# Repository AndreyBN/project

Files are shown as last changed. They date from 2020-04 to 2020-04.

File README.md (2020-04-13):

# project

The controller module board is a universal tool based on the STM32F107VCT6 microcontroller, designed to be integrated into various systems as a control unit.
The controller module has the following parameters:
• STM32F107VCT6 microcontroller: 72 MHz Cortex-M3, 256 Kbytes of program flash memory, 64 Kbytes of RAM, two 12-bit ADCs (16 external channels), two-channel 12-bit DACs, Ethernet MAC 10/100, USB OTG, 2xCAN, 5x USART , 3x SPI, I2C, SDIO, LQFP100 package;
• USB OTG port with mini USB connector;
• 2 CAN interfaces;
• USB bridge - USART to FT232RL;
• 2 RS-232 interfaces or 2 RS-422/485 interfaces with galvanic isolation;
• 10 / 100MBod RMII PHY with Ethernet RJ-45;
• card slots SD / MMC and microSD;
• 16 lines of the microcontroller's PE port are connected to the connector;
• 3 SPI interface connectors for connecting external devices;
• 25 MHz quartz crystal;
• clock quartz resonator 32768 Hz;
• Reset button;
• JTAG connector for connecting a JTAG programmer or debugger;
• supply voltage +9 V or +5 V;
• power supply to the controller core from a 3 V battery;
• overall dimensions: 160x125 mm; landing dimensions: 150x115 mm.

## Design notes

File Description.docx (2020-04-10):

# 1. МОДУЛЬ КОНТРОЛЛЕРА

Плата модуля контроллера является универсальным средством на базе микроконтроллера STM32F107VCT6, предназначенным для встраивания в различные системы в качестве узла управления.

Модуль контроллера имеет следующие параметры:

- микроконтроллер STM32F107VCT6: 72 МГц Cortex-M3, 256 Кбайт флэш-памяти программ, 64Кбайта ОЗУ, два 12-разрядных АЦП (16 внешних каналов), два 12-разрядных ЦАП, Ethernet MAC 10/100, USB OTG, 2xCAN, 5х USART, 3х SPI, I2C, SDIO, корпус LQFP100;
- порт USB OTG с разъемом mini USB;
- 2 CAN интерфейса;
- Мост USB - USART на FT232RL;
- 2 RS-232-интерфейса или 2 RS-422/485-интерфейса с гальванической изоляцией;
- 10/100МБод RMII PHY с разъемом Ethernet RJ-45;
- слоты карт памяти SD/MMC и microSD;
- 16 линий порта PE микроконтроллера выведено на разъем;
- 3 разъема интерфейса SPI для подключения внешних устройств;
- 25 МГц кварцевый резонатор;
- часовой кварцевый резонатор 32768 Гц;
- кнопка сброса Reset;
- разъем JTAG для подключения JTAG-программатора или отладчика;
- напряжение питания +9 В или +5 В;
- питание ядра контроллера от батарейки 3 В;
- габаритные размеры: 160х125 мм; посадочные размеры: 150х115 мм.

Структурная схема модуля контроллера показана на рисунке 1.

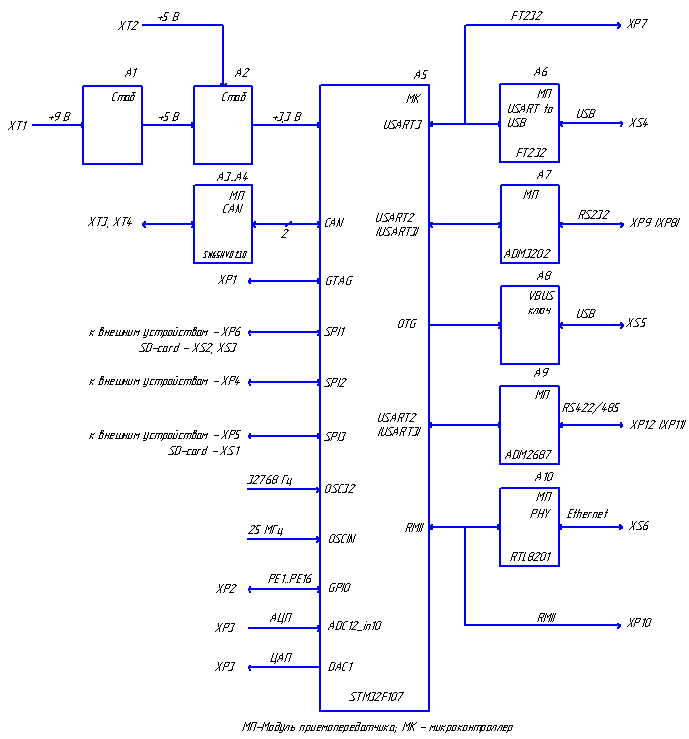
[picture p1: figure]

Рисунок 1 – Структурная схема модуля контроллера

Плата модуля контроллера показана на рисунке 2.

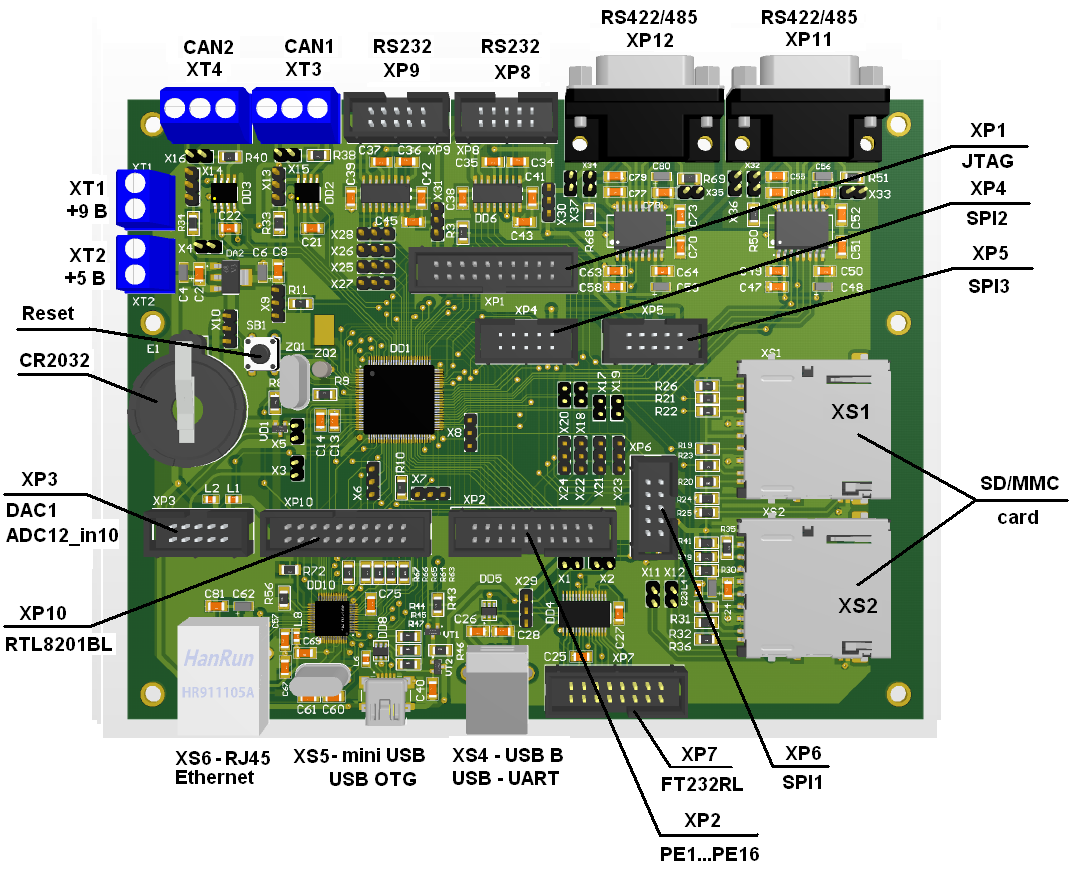
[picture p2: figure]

Рисунок 2 – Плата модуля контроллера

## 1.1 Питание модуля контроллера

Напряжение питания подается через разъемы питания XT1 или XT2. К разъему XT1 подается напряжение от +7,5 до +9 В. К разъему XT2 подается напряжение + 5 В. Для подачи питания +9 В необходимо установить перемычку на X4. Для питания ядра микроконтроллера от батарейки CR2032 необходимо установить перемычку на X10.

Таблица 1 – Установка перемычек на X10

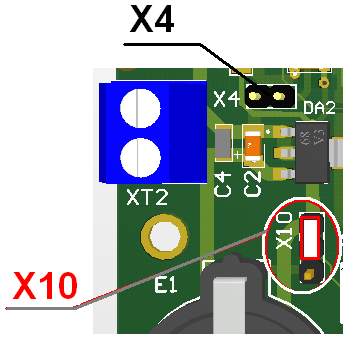
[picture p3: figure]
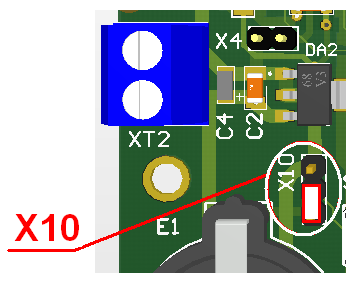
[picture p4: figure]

| Питание ядра от 3,3 В | | Питание ядра от батарейки

## 1.2 Адрес старта микроконтроллера

Кнопка Reset предназначена для сброса микроконтроллера. Установка перемычек на X7 и X9 (рисунок 3) определяет адрес старта микроконтроллера (таблица 2).

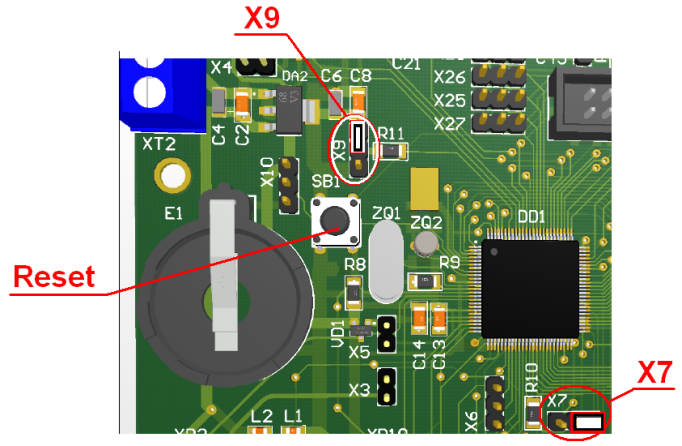
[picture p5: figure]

Рисунок 3 – Установка перемычек на X7 и X9

Таблица 2 – Задание адреса старта микроконтроллера с помощью перемычек X7, X9

X7 (BOOT1) | X9 (BOOT0) | X7 (BOOT1) | X9 (BOOT1) | Функция
| Х | 0 | Х | Программа стартует из основной флэш-памяти (рисунок 3)
| | 1 | 0 | Программа стартует из системной памяти
| | 1 | 1 | Программа стартует из внутреннего ОЗУ

X – любое значение

## 1.3 CAN интерфейс

Установленные на плате микросхемы SN65HVD230 отвечают за преобразование уровней встроенного в микроконтроллер приемопередатчика шины CAN. Структурная схема подключения CAN интерфейса отображена на рисунке 3. Для подключения согласующего резистора R устанавливается перемычка S.

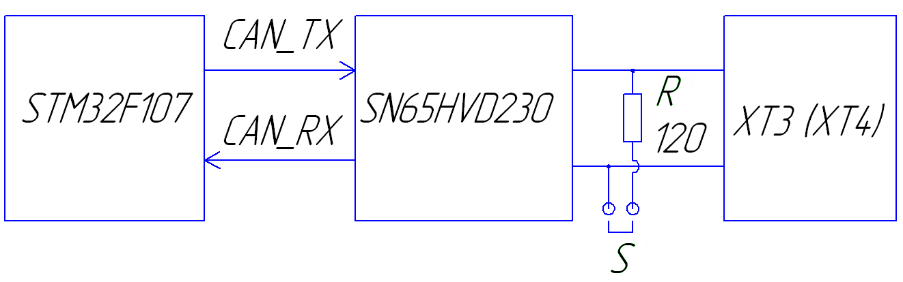
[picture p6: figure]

Рисунок 3 – Структурная схема подключения CAN-интерфейса.

На рисунке 4 показано направление нумерации выводов разъема XT3 и XT4. Для подключения согласующих резисторов устанавливаются перемычки на штыри X15, X16.

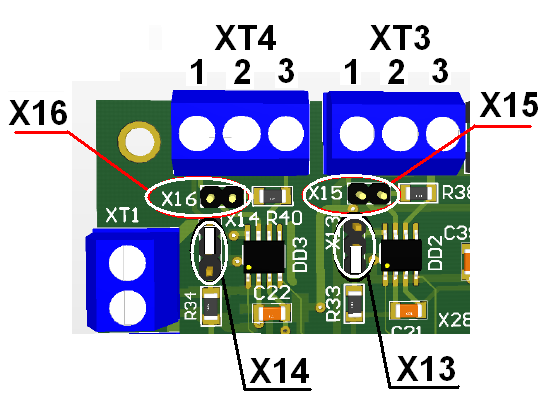
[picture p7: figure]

Рисунок 4 – Направление нумерации выводов разъема XT3 и XT4

Установкой перемычек на штыри X13 и X14 определяет режим работы микросхемы CAN – трансивера.

Таблица 3 – Установка перемычек на X13 и X14

| Высокоскоростной режим работы (Х14 на рисунке 4)
| Режим хранения (Х13 на рисунке 4)

Назначение выводов разъема XT3 (XT4) отображено в таблице 4.

Таблица 4 – Назначение контактов разъема ХT3 (XT4)

Номер контакта | Цепь | Примечание
1 | CANH
2 | GND
3 | CANL

## 1.4 RS232 интерфейс

Установленные на плате микросхемы приемопередатчики ADM3202 отвечают за преобразование уровней встроенного в микроконтроллер приемопередатчика USART в уровни сигналов интерфейса RS232.

Технические характеристики ADM3202:

- Скорость передачи данных 460 кбит/с;
- Конденсаторы накачки заряда 0.1 мкФ;
- Замещение MAX3222/32 и LTC1385;
- Защита от электростатического разряда в соответствии с IEC1000-4-2 (801.2) по выводам RS-232:

±8 кВ: Контактный разряд
±15 кВ: Бесконтактный разряд

Назначение выводов разъемов XP8, XP9 отображено в таблице 5.

Таблица 5 – Назначение контактов разъема ХP8 (XP9)

Номер контакта | Цепь | Примечание
1
2
3 | RS232_RXD
4 | RS232_RTS
5 | RS232_TXD
6 | RS232_CTS
7
8 | +5V
9 | GND
10 | GND

Для питания микросхемы ADM3202 от 3,3 В перемычки выбора напряжения питания Х30 и Х31 должны быть установлена в соответствии с рисунком 5.

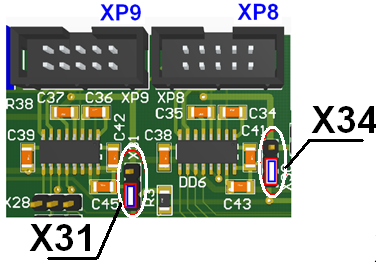
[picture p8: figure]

Рисунок 5 – Установка перемычек на X31 и X34

Для подключения каналов RS232 микроконтроллера необходимо установить перемычки на X21…X24 для подключения к разъему XP8, и на X25…Х28 для подключения к разъему XP9 так, как показано на рисунке 6. Установка перемычек X21…X24 в положение подключает микросхему ADM3202 канала XP8 к приемопередатчику микроконтроллера USART3. Установка перемычек X25…X28 в положение подключает микросхему ADM3202 канала XP9 к приемопередатчику микроконтроллера USART2.

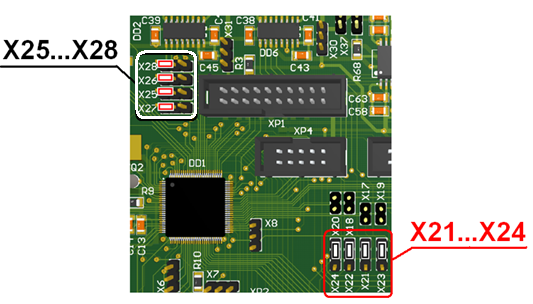
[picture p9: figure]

Рисунок 6 – Установка перемычек на X21…X24 и X25…X28

## 1.5 RS422/485 интерфейс

Установленные на плате микросхемы приемопередатчики ADM2682E отвечают за преобразование уровней встроенного в микроконтроллер приемопередатчика USART в уровни сигналов интерфейса RS422/485.

Изделия ADM2682E/ADM2687E фирмы Analog Devices представляют собой полностью интегральные приёмопередатчики данных с эффективным 5 кВ сигналом и изолированным питанием, имеющие ±15 кВ ESD защиту и пригодные для сверхскоростной связи на многопунктовых линиях передачи.

Каждое из изделий ADM2682E/ADM2687E содержит интегральный изолированный DC-DC преобразователь. В приборах интегрирована технология iCoupler® фирмы Analog Devices, Inc., сочетающая в одном корпусе 3-канальный вентиль, трёхступенчатый дифференциальный драйвер линии, дифференциальный входной приёмник и разработанный фирмой Analog Devices преобразователь постоянного напряжения isoPower®. Микросхема питаются от одиночного источника питания 5 В или 3.3 В, производящего полностью интегральный сигнал, представляя собой RS-422/485 решение с развязкой по цепям питания.

Характерные особенности и преимущества

- Изолированный RS-485/RS-422 приёмопередатчик с эффективным 5 кВ сигналом, с конфигурацией в виде полудуплексной или дуплексной связи;
- Интегральный изолированный преобразователь постоянного напряжения isoPower® ;
- ±15 кВ ESD защита на выводах RS-485 вход/выход;
- Соответствует требованиям стандартов ANSI/TIA/EIA-485-A-98 и ISO 8482:1987(E);
- Питание от 5 В или 3.3 В;
- Соединяет до 256 узлов на одной шине;
- Входы приёмника предохранены от размыкания и КЗ и отказов;
- Высокая стойкость к переходным процессам в синфазном режиме: >25 кВ/мксек;
- Скорость передачи данных: 500 кБит/сек ADM2682E для до 16 Mбит/сек для ADM2687E.

Для подключения интерфейсных микросхем ADM2682E к микроконтроллеру необходимо установить перемычки. Для подключения приемопередатчика USART3 микроконтроллера к микросхеме канала XP11 установить перемычки на X17…X20. Для подключения приемопередатчика USART2 к микросхеме канала XP12 установить перемычки на X25…Х28 в положение , как показано на рисунке 7.

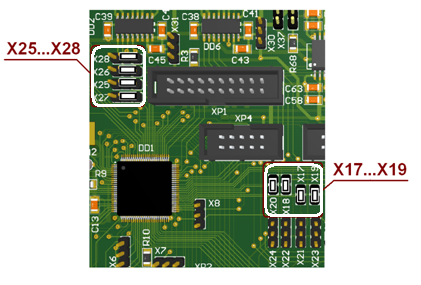
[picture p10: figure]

Рисунок 7 – Установка перемычек на X17…X20 и X25…X28

Назначение выводов разъемов XP11, XP12 (DRB-9MA) отображено в таблице 6.

Таблица 6 – Назначение контактов разъема ХP8 (XP9)

Номер контакта | Цепь | Примечание
1 | RS422/485_TX1+
2 | RS422/485_TX1-
3 | RS422/485_GND
4 | RS422/485_RX1-
5 | RS422/485_RX1+
6 | RS422/485_GND
7 | RS422/485_GND
8 | RS422/485_+5V | Не используется
9 | RS422/485_GND

Структурная схема подключения 4-проводного RS422 – интерфейса показана на рисунке 8. Установкой перемычек подключаются согласующие резисторы.

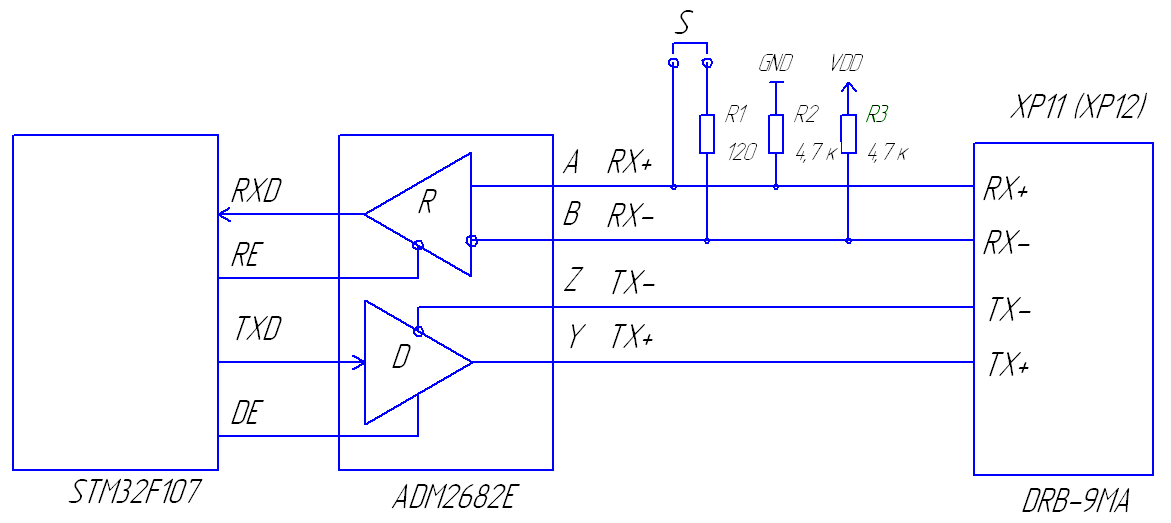
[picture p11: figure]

Рисунок 8 – Структурная схема подключения RS422-интерфейса.

Для подключения к цепям RX+ и RX- каналов XP11 и XP12 согласующего резистора установить перемычки на X34 и X32 в соответствии с рисунком 9.

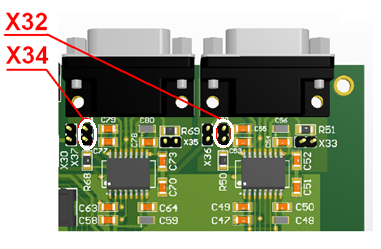
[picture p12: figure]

Рисунок 9 – Установка перемычек на X32 и X34

Примечание. Для реализации 2-проводного RS485 интерфейса необходимо соединить линии RX- и TX- и линии RX+ и TX+ так, как показано на рисунке 10. Для этого соединить в кабельном разъеме контакты 1,5 и 2, 4.

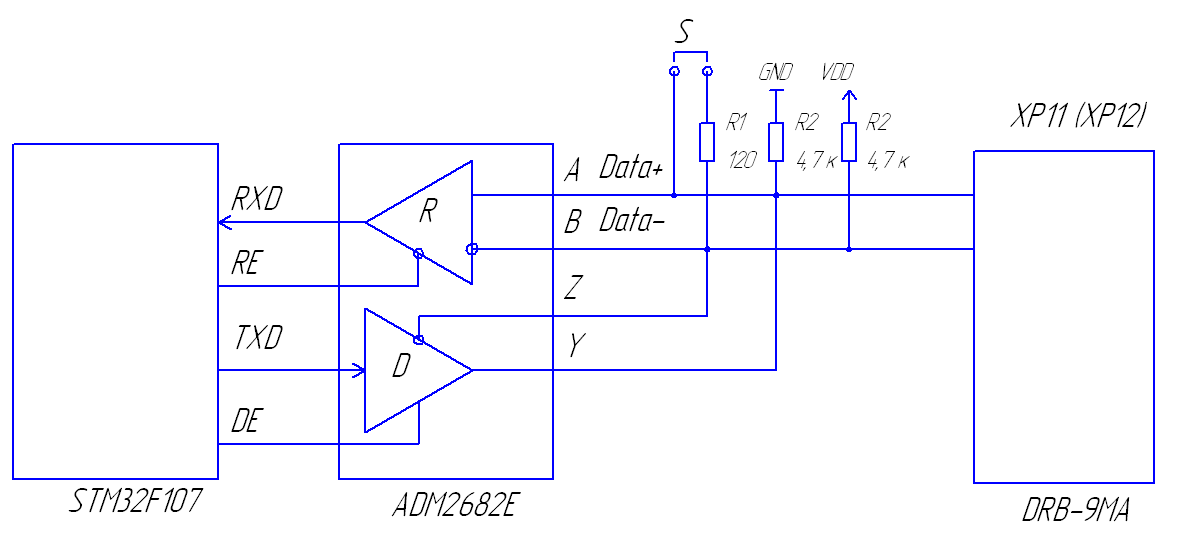
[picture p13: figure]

Рисунок 10 – Структурная схема подключения RS485-интерфейса.

## 1.6 USB - USART преобразователь на FT232RL

Преобразователь USB - USART реализован на микросхеме FT232RL.

Характеристики и особенности микросхемы FT232RL:

- одночиповый переходник из USB в асинхронный последовательный интерфейс передачи данных (UART);
- протокол USB полностью реализован в микросхеме;
- интерфейс UART поддерживает режимы передачи 7 и 8 бит данных, 1 и 2 стоповых бита, различные режимы контроля четности;
- скорости передачи от 300 бод до 3 мегабод для RS422 /RS485 / TTL и от 300 бод до 1 мегабод для RS-232;
- новые настраиваемые выводы CBUS;
- возможность вывода состояния приема/передачи на внешние светодиоды;
- возможность подачи тактового сигнала на внешние микросхемы, контроллеры, ПЛИС, частоты 6, 12, 24 и 48 МГц;
- высокая нагрузочная способность выходов;
- встроенная энергонезависимая память EEPROM объемом 1024 байт;

Для подключения микросхемы FT232RL к последовательному порту микроконтроллера USART3 необходимо установить перемычки на X21…X24 в соответствии с рисунком 11.

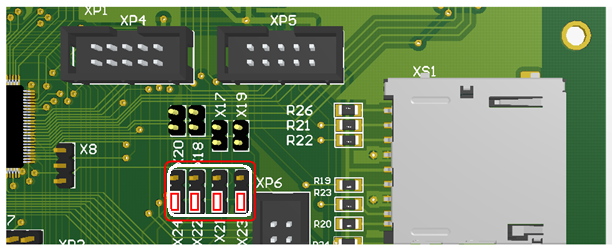
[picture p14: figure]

Рисунок 11 – Установка перемычек на X21…X24

Назначение выводов разъема USB XS4 отображено в таблице 7.

Таблица 7 – Назначение контактов разъема XS4

Номер контакта | Цепь | Примечание
1 | VUSB
2 | D-
3 | D+
4 | GND
5 | SHIELD
6 | SHIELD

Для выбора напряжения питания 3,3 В или 5 В необходимо установить перемычку X29 в требуемое положение в соответствии с таблицей 8.

Таблица 8 – Установка перемычек на X29

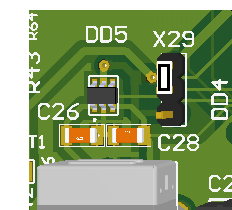
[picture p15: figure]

Питание от VUSB | | Питание от 3,3 В

Все выводы микросхемы FT232RL выведены на специальный разъем XP7, назначение выводов которого отображено в таблице 9.

Таблица 9 – Назначение контактов разъема ХP8

Номер контакта | Цепь | Примечание
1 | FT232_DTR
2 | FT232_RRS
3 | FT232_RI
4
5 | FT232_DCD
6 | FT232_DSR
7 | FT232_CBUS4
8 | FT232_CTS
9 | FT232_CBUS3
10 | FT232_CBUS2
11 | FT232_CBUS0
12 | FT232_CBUS1
13 | FT232_VCC
14 | FT232_GND
15 | FT232_VCC
16 | FT232_GND

## 1.7 Ethernet

В плате модуля контроллера применена микросхема Ethernet RTL8201BL, подключенная по интерфейсу MII (Media Independent Interface). Тактирование RTL8201BL производится от кварцевого резонатора с частотой 25,0МГц. Схема подключения микросхемы показана на рисунке 12.

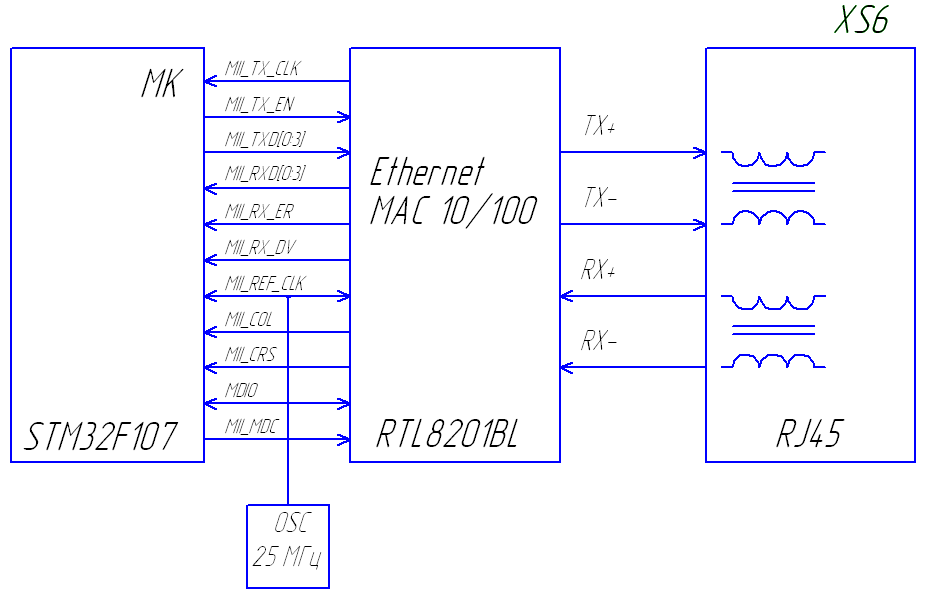
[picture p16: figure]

Рисунок 12 – Схема подключения микросхемы Ethernet PHY RTL8201BL

Сигналы управления микросхемой RTL8201BL выведены на внешний разъем XP10 (рисунок 1).

Таблица 10 – Назначение контактов разъема ХP10

Номер контакта | Цепь | Примечание
1 | Eth_MII_TX_CLK
2 | Eth_MII_TX_EN
3 | Eth_MII_TX_D0
4 | Eth_MII_TX_D1
5 | Eth_MII_TX_D2
6 | Eth_MII_TX_D3
7 | Eth_MII_RX_D0
8 | Eth_MII_RX_D1
9 | Eth_MII_RX_D2
10 | Eth_MII_RX_D3
11 | Eth_MII_RX_ER
12 | Eth_MII_RX_DV
13 | Eth_MII_CLK
14 | Eth_MII_RX_COL
15 | Eth_MII_RX_CRS
16 | Eth _MDC
17 | Eth_MII_MDIO
18 | RESET
19 | +3,3V
20 | GND

Примечание. Сигнал Eth_MII_RX_DV подключается установкой перемычки на X6, а сигнал Eth_MII_TXD1 на Х8 в соответствие с рисунком 13.

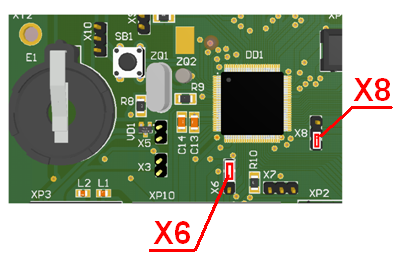
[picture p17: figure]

Рисунок 13 – Установка перемычек на X6 и X8 для подключения сигналов Eth_MII_RX_DV и Eth_MII_TXD1

Внимание! Микроконтроллер STM32F107VCT6 не позволяет одновременно использовать Ethernet и USB.

Для соединения отладочной платы с концентратором или компьютером на плате установлен стандартный разъем RJ-45 (XS6) LU1T516-43LF со встроенными Ethernet-фильтрами. Назначение его выводов отображено в таблице 11.

Таблица 11 – Назначение контактов разъема ХS6 (RJ45)

Номер контакта на плате | Цепь | | Номер контакта на разъеме
1 | TX+ | Выход передатчика + | 1
2 | TX- | Выход передатчика - | 2
3 | CT | Общий провод | 4, 5
4
5
6 | CT | Общий провод | 6, 7
7 | RХ+ | Вход передатчика + | 3
8 | RХ- | Вход передатчика - | 6
9 | HL1+ | Светодиод 1 +
10 | HL1- | Светодиод 1 -
11 | HL2- | Светодиод 2 -
12 | HL2+ | Светодиод 2 +
13 | SHIELD | Корпус
14 | SHIELD | Корпус

## 1.8 USB интерфейс

USB-порт отладочной платы может работать в одном из трех режимов: Host, Device или OTG (On-The-Go). Сигналы интерфейса USB выведены на разъем mini USB XS5. Назначение выводов разъема USB XS5 отображено в таблице 12.

Таблица 12 – Назначение контактов разъема XS5 (USB/M – 1J)

Номер контакта | Цепь | Примечание
1 | VUSB
2 | D-
3 | D+
4 | ID
5 | GND
6 | SHIELD
7
8
9

## 1.9 Карты памяти SD и MicroSD

Плата поддерживает работу с картами памяти SD, SDHC и microSD, microSDHC. Схема подключения карты памяти по интерфейсу SPI показана на рисунке 14.

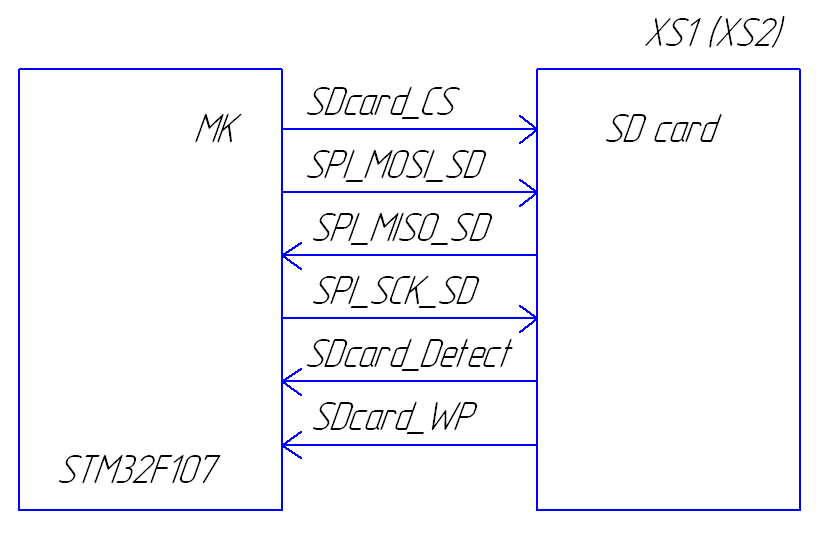
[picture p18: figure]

Рисунок 14 – Схема подключения карты памяти по интерфейсу SPI

Предусмотрена функция определения наличия карты в держателе путем опроса линии SDcard_Detect на логический 0. При корректно установленной карте памяти линия SDcard_Detect соединяется с общей шиной встроенным коммутатором держателя AXA2R73361. Линия SDcard_WP также соединяется с общей шиной в случае, если запись данных на карту памяти разрешена. Линии SDcard_Detect и SDcard_WP подтянуты к напряжению питания +3,3 В, что позволяет избежать конфликтов в случае, если пользователь не сконфигурирует порты ввода вывода.

Карты памяти SD, SDHC устанавливается в держатель XS1 (AXA2R73361), подключенный по интерфейсу SPI3, и держатель XS2 (AXA2R73361), подключенный по интерфейсу SPI1. Для подключения сигналов SDcard_Detect и SDcard_WP к разъему XS2 необходимо установить перемычки на X11 и X12 в соответствии с рисунком 15.

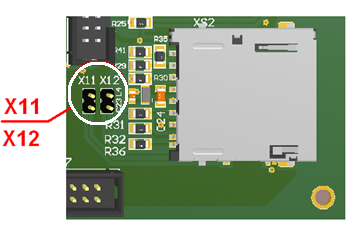
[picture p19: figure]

Рисунок 15 – Установка перемычек на X11 и X12 для подключения сигналов SDcard_Detect и SDcard_WP к разъему XS2

Назначение выводов разъемов XS1, XS2 отображено в таблицах 13, 14.

Таблица 13 – Назначение контактов разъема XS1 (AXA2R73361)

Номер контакта | Цепь | Обозначение
9 | +3,3V (HL) | DAT2/RES
1 | CS1/BUSY/RESET3 ((SDcard_CS) | CD/DAT3/CS
2 | SPI3_MOSI | CMD/DI
3 | GND | VSS1
4 | +3,3V | VDD
5 | SPI3_SCK | CLK
6 | GND | VSS2
7 | SPI3_MISO | DAT0/D0
8 | +3,3V (HL) | DAT1/RES
10 | SP3_RDY (SDcard_Detect) | CD
11 | SP3_CS (SDcard_WP) | WP
12 | GND | COMM

Таблица 14 – Назначение контактов разъема XS2 (AXA2R73361)

Номер контакта | Цепь | Обозначение
9 | +3,3V (HL) | DAT2/RES
1 | SDCard_CS | CD/DAT3/CS
2 | SPI1_MOSI_SD | CMD/DI
3 | GND | VSS1
4 | +3,3V | VDD
5 | SPI1_SCK_SD | CLK
6 | GND | VSS2
7 | SPI1_MISO_SD | DAT0/D0
8 | +3,3V (HL) | DAT1/RES
10 | SDcard_Detect | CD
11 | SDcard_WP | WP
12 | GND | COMM

Карты памяти microSD, microSDHC устанавливаются в держатель DM3AT-SF-PEJM5 XS3, подключенный к интерфейсу SPI1. Разъем XS3 расположен на обратной стороне платы. Для подключения сигнала SDcard_Detect к разъему XS3 перемычка на X11 должна быть установлена.

Таблица 15 – Назначение контактов разъема XS3 (DM3AT-SF-PEJM5)

Номер контакта | Цепь | Обозначение
1 | | DAT2
2 | SDCard_CS | CD/DAT3
3 | SPI1_MOSI_SD | CMD
4 | +3,3V | VDD
5 | SPI1_SCK_SD | CLK
6 | GND | VSS
7 | SPI1_MISO_SD | DAT0
8 | | DAT1
9 | SDcard_Detect | CD
10 | | COMM

Примечание. Для подключения сигнала SPI1_MOSI_SD к разъему XS2 и XS3 необходимо установить перемычку на X6 в соответствии с рисунком 16.

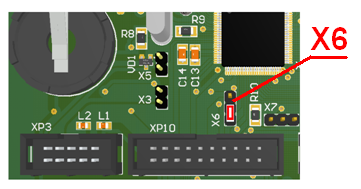
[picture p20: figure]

Рисунок 16 – Установка перемычки на X6 для подключения сигнала SPI1_MOSI_SD к разъемам XS2, XS3, XP6

## 1.10 SPI интерфейс

Кроме подключения SD – карт сигналы SPI интерфейса выведены на внешние разъемы XP4…XP6 (рисунок 2). Тип разъемов BH-10. По интерфейсу SPI могут быть подключены внешние узлы: АЦП, ЦАП, датчики и т. д.

Интерфейс SPI1 подключается к разъему XP6. Назначение выводов разъемов XP6 отображено в таблице 16.

Таблица 16 – Назначение контактов разъема XP6

Номер контакта | Цепь | Примечание
1 | +3,3V
2 | GND
3
4
5 | SDcard_WP
6 | SDcard_Detect
7 | SPI1_MISO_SD
8 | SPI1_MOSI_SD
9 | SPI1_SCK_SD
10 | SDCard_CS

Примечание. Для подключения сигнала SPI1_MOSI_SD к разъему XP6 необходимо установить перемычку на Х6 в соответствии с рисунком 16.

Интерфейс SPI2 подключается к разъему XP4. Назначение выводов разъемов XP4 отображено в таблице 17.

Таблица 17 – Назначение контактов разъема XP4

Номер контакта | Цепь | Примечание
1 | +3,3V
2 | GND
3 | SPI2_RDY
4 | SPI2_CS
5 | CS1/BUSY/RESET2
6 | SPI2_CONVST_RDY
7 | SPI2_MISO
8 | SPI2_MOSI
9 | SPI2_SCK
10 | SPI2_CS2_SYNC

Примечание. Для подключения сигнала SPI2_SCK к разъему XP4 необходимо установить перемычку на Х8 в соответствии с рисунком 17.

Рисунок 17 – Установка перемычки на X6 для подключения сигнала SPI2_SCK к разъему XP4

Интерфейс SPI3 подключается к разъему XP5. Назначение выводов разъемов XP4 отображено в таблице 18.

Таблица 18 – Назначение контактов разъема XP5

Номер контакта | Цепь | Примечание
1 | +3,3V
2 | GND
3 | SPI3_RDY
4 | SPI3_CS
5 | CS1/BUSY/RESET3
6 | SPI3_CONVST_RDY
7 | SPI3_MISO
8 | SPI3_MOSI
9 | SPI3_SCK
10 | SPI3_CS2_SYNC

## 1.11 Разъем XP3

К разъему XP3 выведены сигналы АЦП и ЦАП микроконтроллера. Назначение выводов разъемов XP3 отображено в таблице 19.

Таблица 19 – Назначение контактов разъема XP3

Номер контакта | Цепь | Обозначение
1 | +3,3V | +3,3V
2 | GND | GND
3 | +5V | +5V
4 | PC6
5 | PC7
6
7 | ADC12_IN6 | TADC0
8 | DAC_OUT1 | MPDAC0
9 | DAC_OUT1 | MPDAC1
10 | ADC12_IN10 | TADC1

Примечание. Для подключения сигнала ADC12_IN6 к разъему XP3 необходимо установить перемычку на Х3, которая соединяет линию ADC12_IN6 с линией SPI1_MISO_SD (порт PA6) в соответствии с рисунком 18.

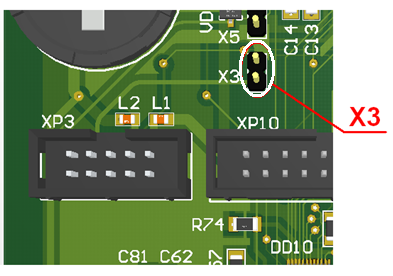
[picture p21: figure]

Рисунок 18 – Установка перемычки на X3 для подключения сигнала ADC12_IN6 к разъему XP3

## 1.12 Разъем XP2

К разъему XP2 выведены сигналы порта PE. Назначение выводов разъемов XP3 отображено в таблице 19.

Таблица 19 – Назначение контактов разъема ХP2

Номер контакта | Цепь | Порт МК | Номер вывода МК | Примечание
1 | DD0 | PE0 | 97
2 | DD1 | PE1 | 98
3 | DD2 | PE2 | 1
4 | DD3 | PE3 | 2
5 | DD4 | PE4 | 3
6 | DD5 | PE5 | 4
7 | Date_DD6 | PE6 | 5
8 | CLK_DD7 | PE7 | 38
9 | MP_PE1 | PE8 | 39
10 | MP_PE2 | PE9 | 40
11 | MP_DAC01 | PE10 | 41
12 | MP_DACOK | PE11 | 42
13 | MP_DACRK | PE12 | 43
14 | MP_RelTest | PE13 | 44
15 | MP_KSSOUT | PE14 | 45
16 | MP_KSSIN | PE15 | 46
17 | +3,3 V
18 | GND
19 | +5 V
20 | GND

Цепи питания +3,3V и +5V подключаются через перемычки, устанавливаемые на X1 и X2 в соответствии с рисунком 19.

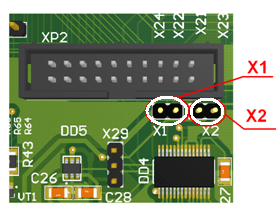
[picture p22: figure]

Рисунок 19 – Установка перемычки на X1, X2 для подключения цепей питания +3,3V и +5V

## 1.13 Программирование и отладка

Для программирования и отладки предназначен разъем JTAG XP1, назначение выводов которого отображено в таблице 20.

Таблица 20 – Назначение контактов разъема ХP1

Номер контакта | Цепь | Примечание
1 | +3,3V
2 | +3,3V
3 | TRST
4 | GND
5 | TDI
6 | GND
7 | TMS/SWDIO
8 | GND
9 | TCK/SWCLK
10 | GND
11
12 | GND
13 | TDO/SWO
14 | GND
15 | RESET
16 | GND
17 | NC
18 | GND
19 | NC
20 | GND

## 1.14 Распределение сигналов микроконтроллера STM32F107 по периферийным модулям

Функциональное назначение выводов микроконтроллера STM32F107 отображено в таблице 21.

Таблица 21 – Распределение сигналов микроконтроллера STM32F107 по периферийным модулям.

Модуль | Сигналы | Порт | Выводы | Примечание
CAN1 | CAN1_RX | PD0 | 81
| CAN1_TX | PD1 | 82
CAN2 | CAN2_RX | PB5 | 91
| CAN2_TX | PB6 | 92
SPI1 | SPI1_SCK_SD | PA5 | 30
| SPI1_MISO_SD | PA6 | 31
| SPI1_MOSI_SD | PA7 | 32
| SDCard_CS | PA8 | 67
| SDCard_Detect | PC7 | 64
| SDCard_WP | PC8 | 65
SPI2 | SPI2_SCK | PB13 | 52
| SPI2_MISO | PB14 | 53
| SPI2_MOSI | PB15 | 54
| SPI2_CS | PB9 | 96
| SPI2_CS2_SYNC | PC6 | 63
| SPI2_RDY | PD2 | 83
| CS1/BUSY/RESET2 | PC13 | 7
SPI3 | SPI3_SCK | PC10 | 78
| SPI3_MISO | PC11 | 79
| SPI3_MOSI | PC12 | 80
| SPI3_CS | PD14 | 61
| SPI3_CS2_SYNC | PD7 | 88
| SPI3_RDY | PD13 | 60
| CS1/BUSY/RESET3 | PD15 | 62
USART2 | USART2_CTS | PD3 | 84
| USART2_RTS | PD4 | 85
| USART2_TX | PD5 | 86
| USART2_RX | PD6 | 87

Таблица 21 (Продолжение) – Распределение сигналов микроконтроллера STM32F107 по периферийным модулям.

USART3 | USART3_CTS | PD11 | 58
| USART3_RTS | PD12 | 59
| USART3_TX | PD8 | 55
| USART3_RX | PD9 | 56
USB OTG | USB_Power_On | PC9 | 66
| USB_VBUS | PA9 | 68
| USB_ID | PA10 | 69
| USB_DM | PA11 | 70
| USB_DP | PA12 | 71
MII Ethernet | Eth_MII_TX_CLK | PC3 | 18
| Eth_MII_TX_EN | PB11 | 48
| Eth_MII_TX_D0 | PB12 | 51
| Eth_MII_TX_D1 | PB13 | 52
| Eth_MII_TX_D2 | PC2 | 17
| Eth_MII_TX_D3 | PB8 | 95
| Eth_MII_RX_D0 | PC4 | 33
| Eth_MII_RX_D1 | PC5 | 34
| Eth_MII_RX_D2 | PB0 | 35
| Eth_MII_RX_D3 | PB1 | 36
| Eth_MII_RX_ER | PB10 | 47
| Eth_MII_RX_DV | PA7 | 32
| Eth_MII_CLK | PA1 | 24
| Eth_MII_RX_COL | PA3 | 26
| Eth_MII_RX_CRS | PA0 | 23
| Eth _MDC | PC1 | 16
| Eth_MII_MDIO | PA2 | 25
DAC | DAC_OUT1 | PA4
ADC | ADC12_IN10 | PC0 | 15
| ADC12_IN6 | PA6 | 31

## 1.15 Размещение компонентов

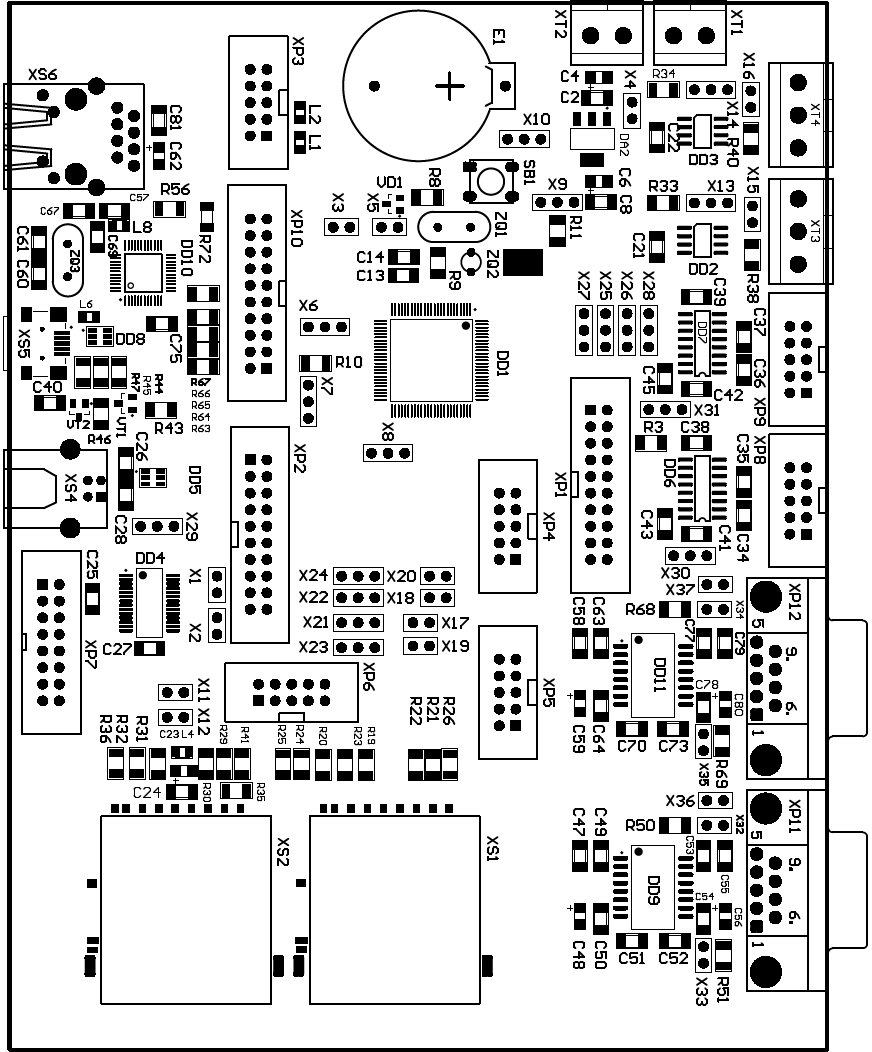
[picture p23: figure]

Рисунок 20 – Плата модуля контроллера, вид сверху

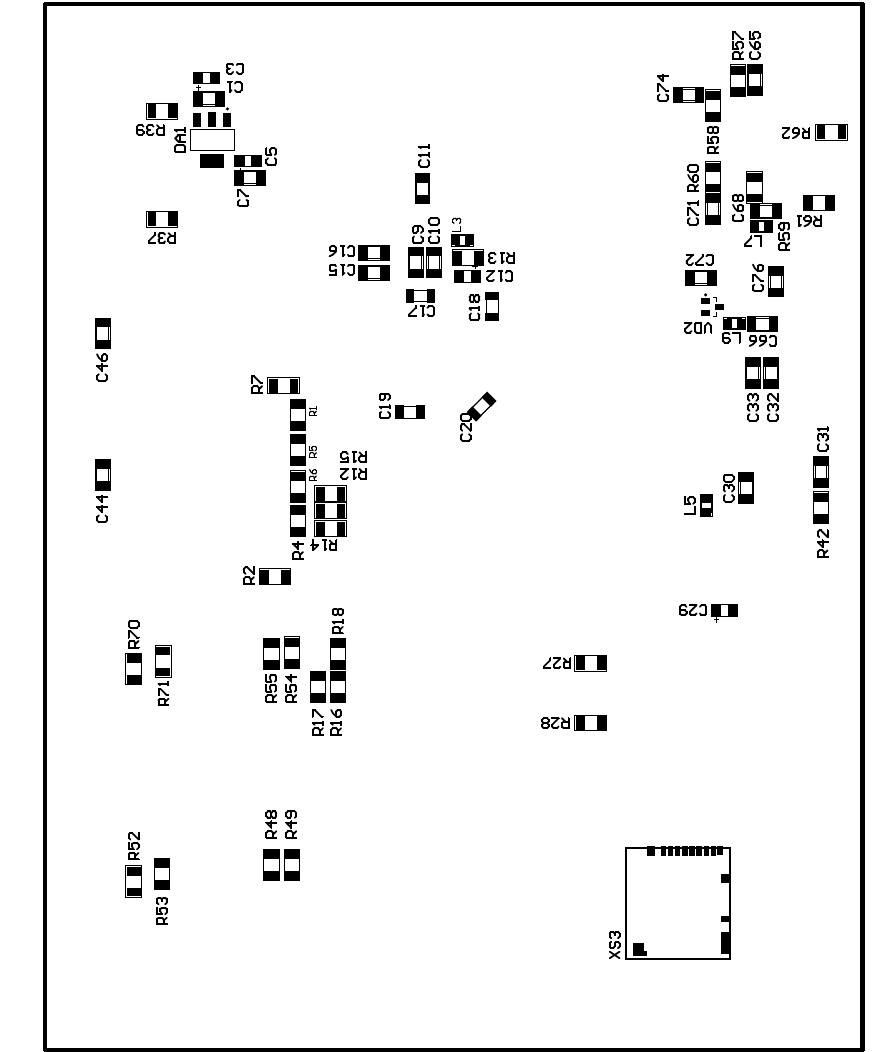
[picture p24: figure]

Рисунок 21 – Плата модуля контроллера, вид снизу

## 1.16 Перечень элементов

Таблица 22 – Перечень элементов

Обозначение на схеме | Параметр | Кол.
C1, C2, C7, C8, C11, C13, C14, C17...C22, C24, C25, C27, C30, C34...C47, C51, C52, C54, C55, C57, C58, C65...C76, C78, C79, C81 | 0,1 мк | 52
C3, C4, C12, C23, C29, C48, C56, C59, C80 | 10 мк | 9
C5, C6, C62 | 22 мк | 3
C9, C10, C60, C61 | 22 | 4
C15, C16 | 15 | 2
C26, C28 | 47 | 2
C31 | 4700 | 1
C32, C33 | 0,047 мк | 2
C49, C50, C53, C63, C64, C77 | 0,01 мк | 6
DA1 | LM1117MPX-5 | 1
DA2 | LM1117MPX-3,3 | 1
DD1 | STM32F107VCT6 | 1
DD2, DD3 | SN65HVD230DR | 2
DD4 | FT232RL | 1
DD5, DD8 | USBLC6-2SC6 | 2
DD6, DD7 | ADM3202ARNZ | 2
DD9, DD11 | ADM2687EBRIZ | 2
DD10 | RTL8201BL | 1
E1 | BH800 | 1
L1, L2 | BLM21PG331SH1D | 2
L3…L7 | BLM21AG151SN1D | 5
L8, L9 | TL201209 4R7K | 2
R1…R8, R10, R11, R20, R26…R28, R36, R37, R39, R41, R43, R46, R48, R49, R54, R55 | 10 к | 24
R9 | 220 | 1
R12, R14…R18, R35, R52, R53, R63…R67, R70…R72 | 4,7 к | 17
R13 | 47 | 1
R19…R25, R29…R32 | 100 | 10
R33, R34, R56 | 2,2 к | 3
R38, R40, R50, R51, R68, R69 | 120 | 6
R42 | 1 M | 1
R44, R45 | 22 | 2
R47, R61, R62 | 200 | 3
R57…R60 | 49,9 | 4
SB1 | SWT-2 | 1
VD1 | BAT54S | 1
VD2 | BAT54A | 1
VT1 | BC846AMTF | 1
VT2 | IRLML2502 | 1
X1…X5, X11, X12, X15…X19, X20, X32…X37 | PLS-02 | 19
X6…X10, X13, X14, X21…X31 | PLS-03 | 18
XP1, XP2, XP10 | BH-20 | 3

Таблица 22 (Продолжение) – Перечень элементов

Обозначение на схеме | Параметр | Кол.
XP3…XP6, XP8, XP9 | BH-10 | 6
XP7 | BH-16 | 1
XP11, XP12 | DB-9MA | 2
XS1, XS2 | AXA2R73361 | 2
XS3 | DM3BT-DSF-PEJS | 1
XS4 | USBB-1J | 1
XS5 | USB/M-1J | 1
XS6 | LU1T516-43LF | 1
XT1, XT2 | TB-01A | 2
XT3, XT4 | TB-01B | 2
ZQ1, ZQ3 | 25 МГц | 2
ZQ2 | 32768 | 1

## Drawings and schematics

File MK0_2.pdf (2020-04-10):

DD1

C15

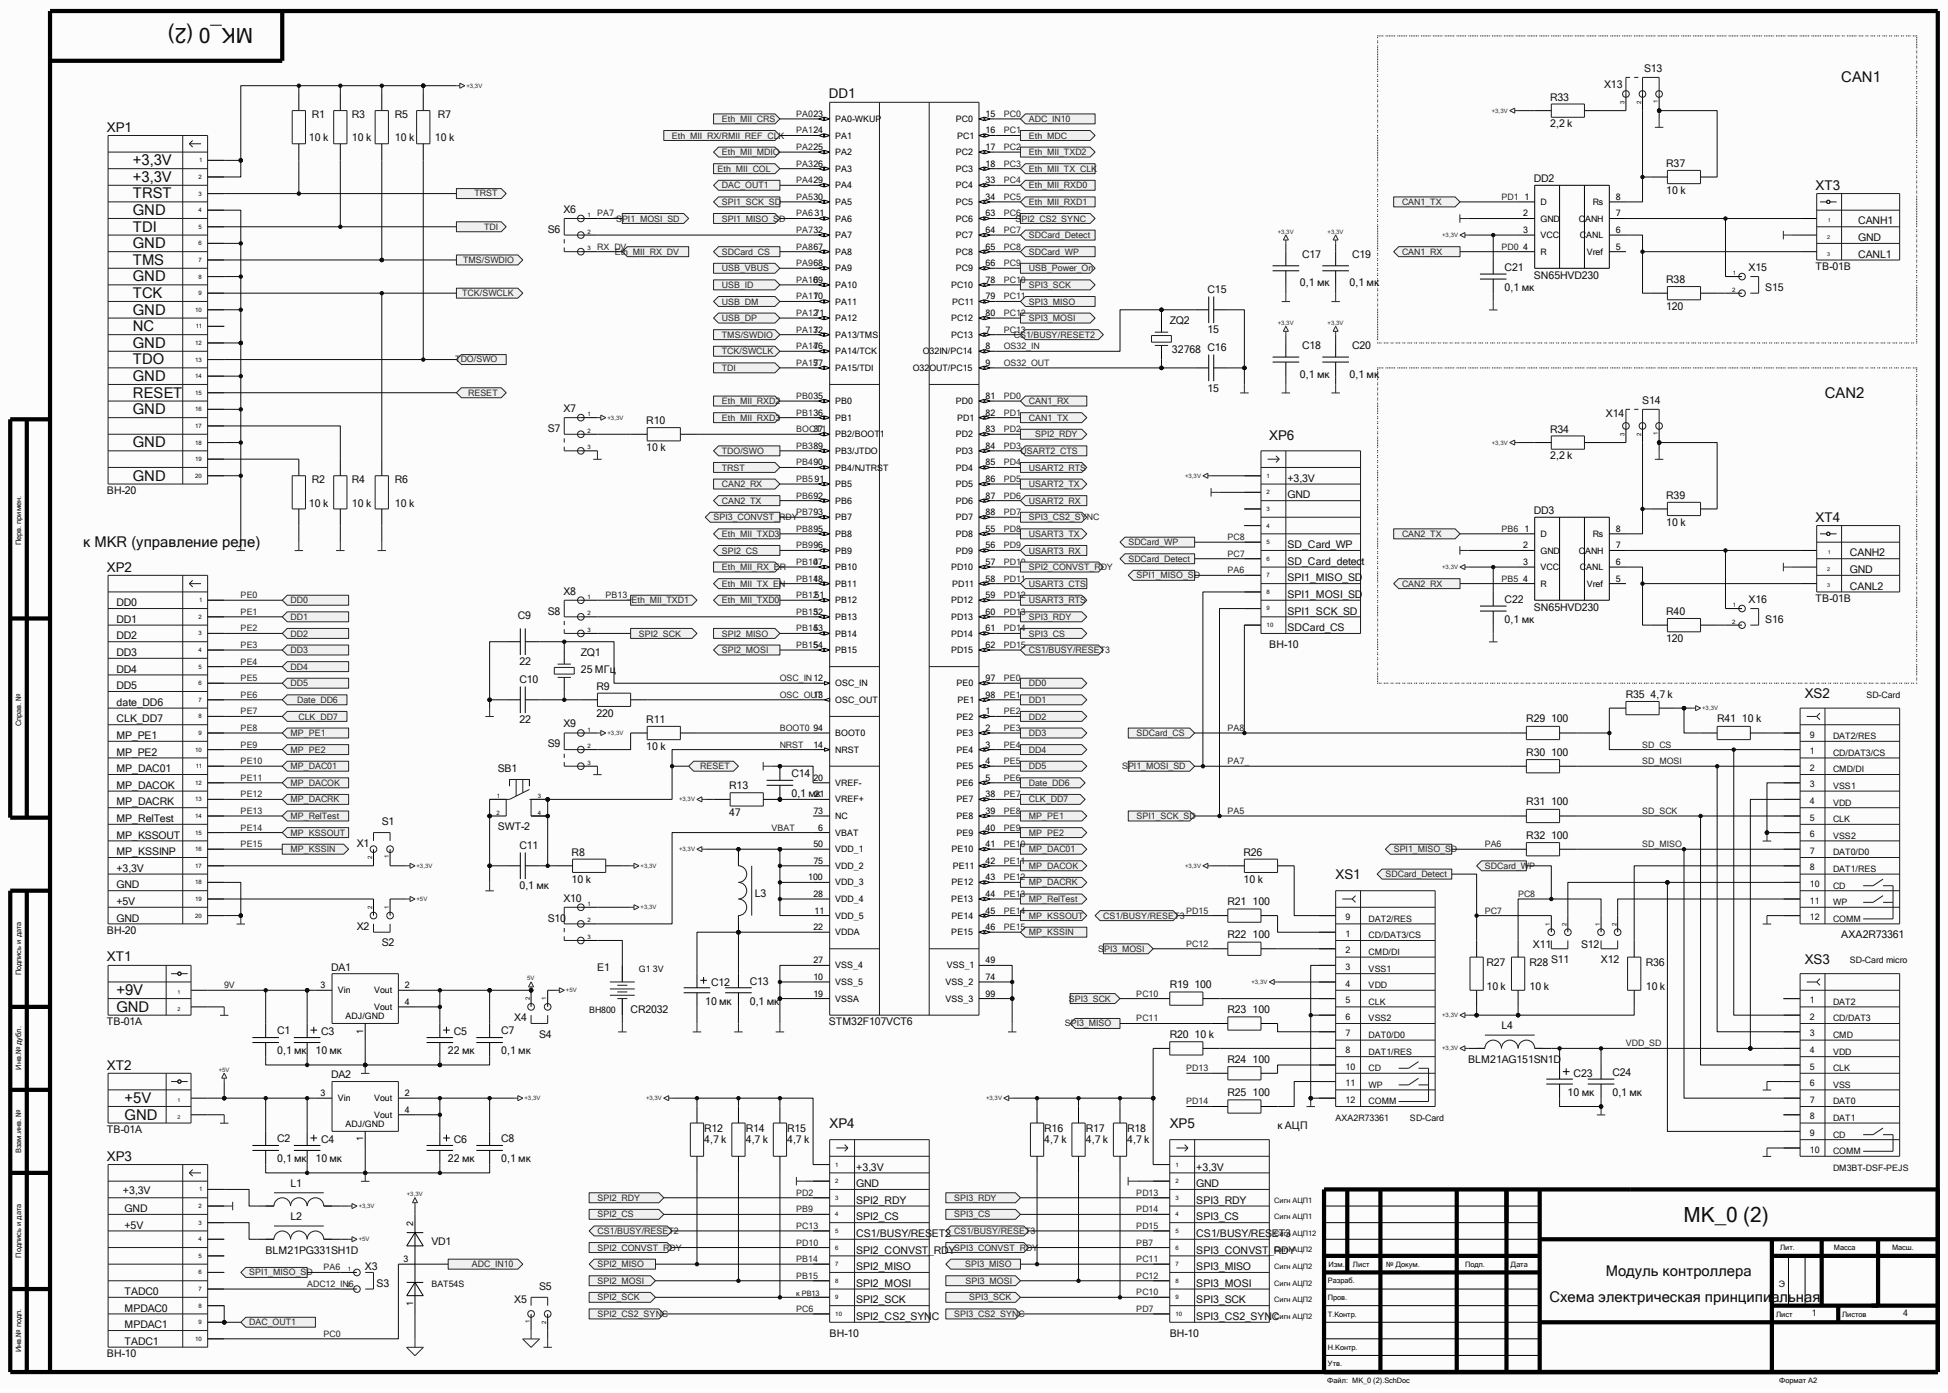
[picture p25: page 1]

1 | CANH1

2 | GND

3 | CANL1

Лит. Инв.№ подп. Подпись и дата Взам.инв. № Справ. № Перв. примен.

1 | CANH2

3 | CANL2

DD0 | 1
DD1 | 2
DD2 | 3
DD3 | 4
DD4 | 5
DD5 | 6
date_DD6 | 7

VSS_4 27 VSS_5 10 | R19 100

2 | CMD/DI

4 | VDD

10 | COMM

GND | 2

TADC0 | 7

MPDAC0 | 8

MPDAC1 | 9

TADC1 | 10

Н.Контр.

Утв.

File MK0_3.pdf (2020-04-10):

## USART to USB

DD6

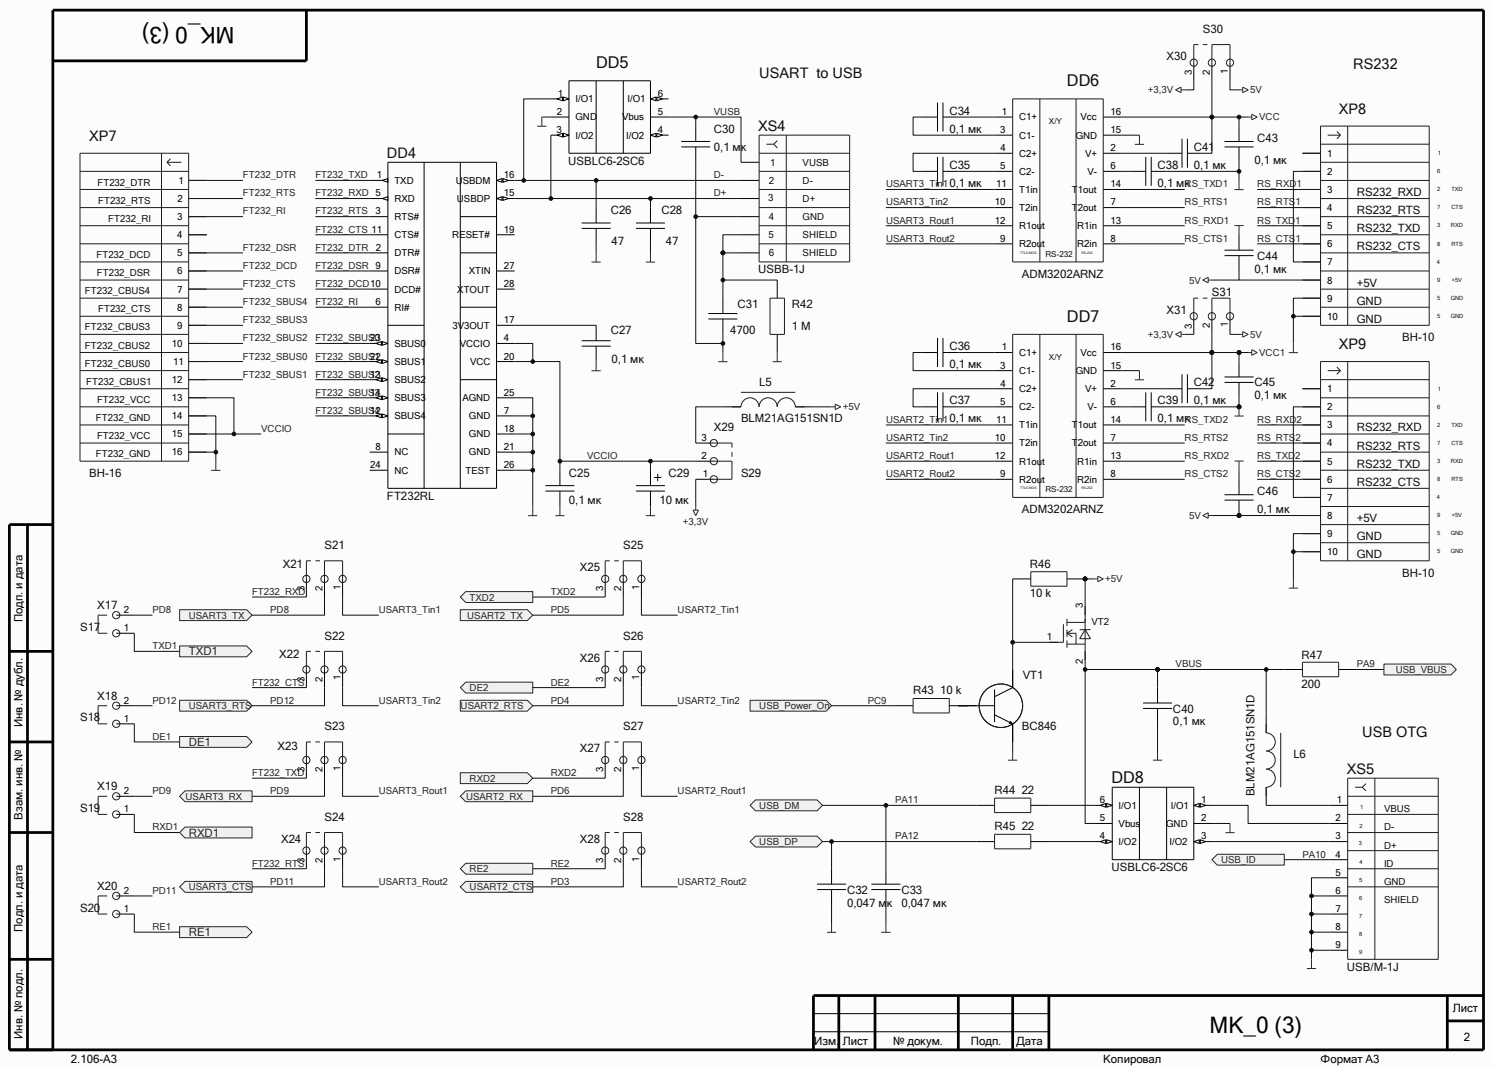
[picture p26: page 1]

4 | RS232_RTS
5 | RS232_TXD
6 | RS232_CTS
8 | +5V
9 | GND

FT232_DSR | 6
FT232_CBUS4 | 7
FT232_CTS | 8
FT232_CBUS3 | 9

10 | GND

Инв. № подл. Инв. № дубл. Подп. и дата Взам. инв. № Подп. и дата

3 | D+
4 | ID
5 | GND
6 7 8 9 | SHIELD

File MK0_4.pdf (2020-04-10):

DD10

Ethernet | 1

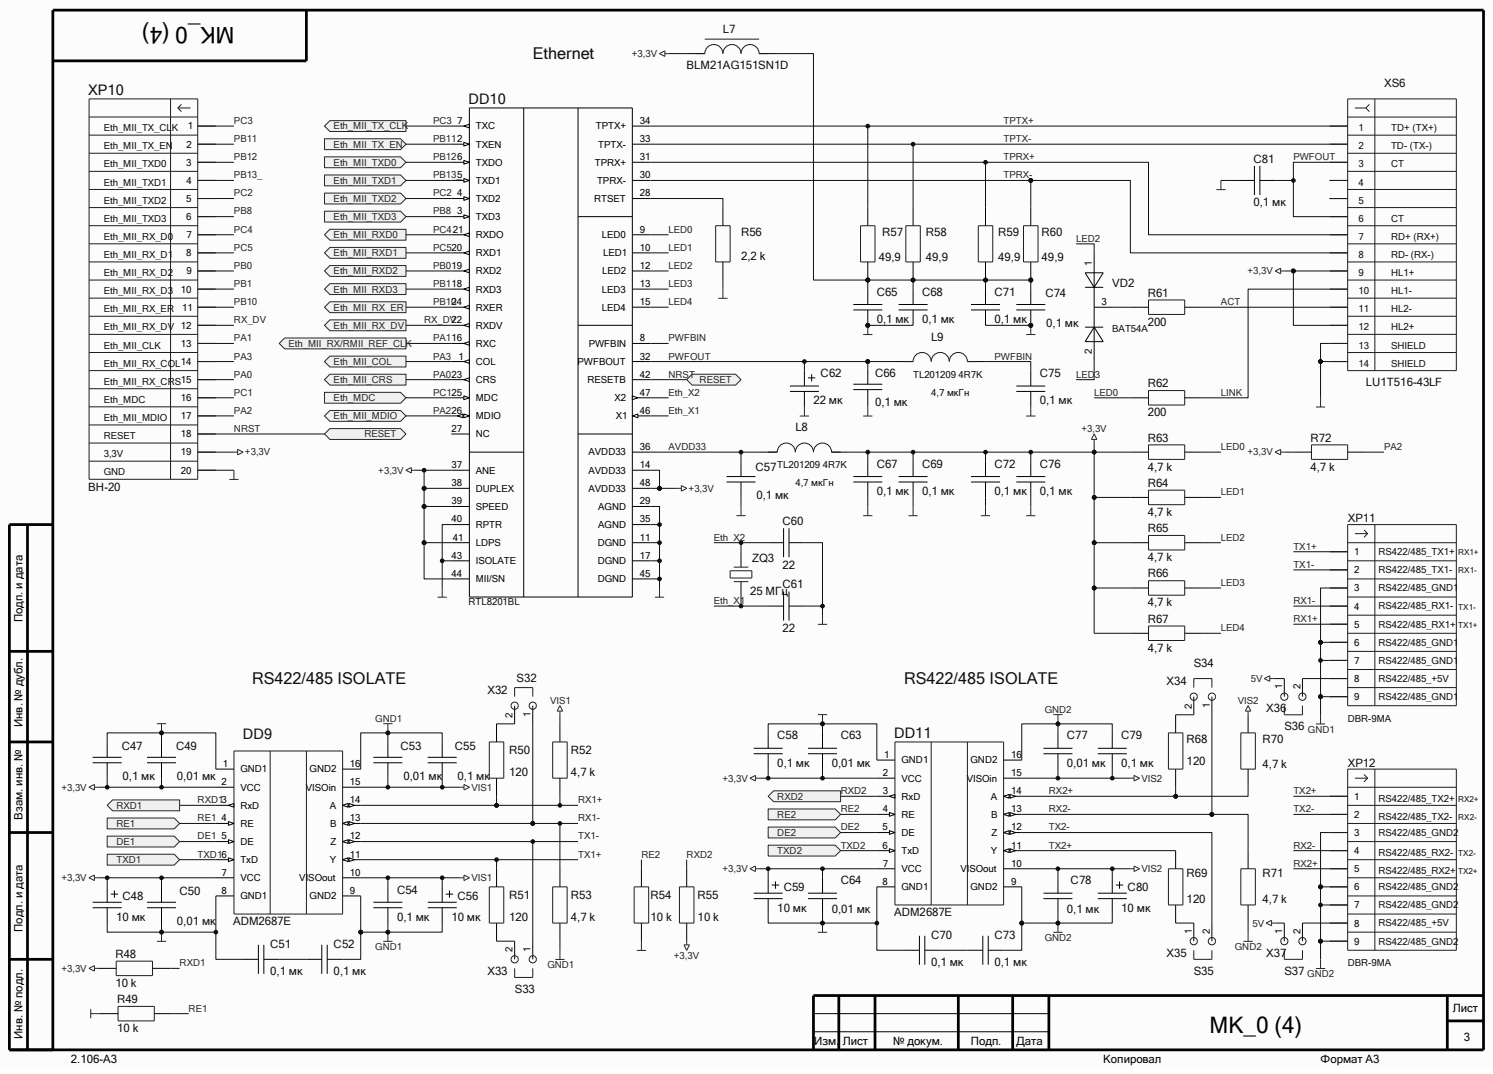
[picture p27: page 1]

Eth_MII_RX_CRS | 15
Eth_MDC | 16

Инв. № подл. Инв. № дубл. Подп. и дата Взам. инв. № Подп. и дата

5 | RS422/485_RX1+
6 | RS422/485_GND1
7 | RS422/485_GND1
8 | RS422/485_+5V
9 | RS422/485_GND1

GND1 1 VCC 2 RxD 3 RE 4 DE 5 TxD 6 VCC 7 | A B Z Y

DE 5 | 12 TX2-TX2+
TxD 6 | 11

5 | RS422/485_RX2+
6 | RS422/485_GND2
7 | RS422/485_GND2
9 | RS422/485_GND2

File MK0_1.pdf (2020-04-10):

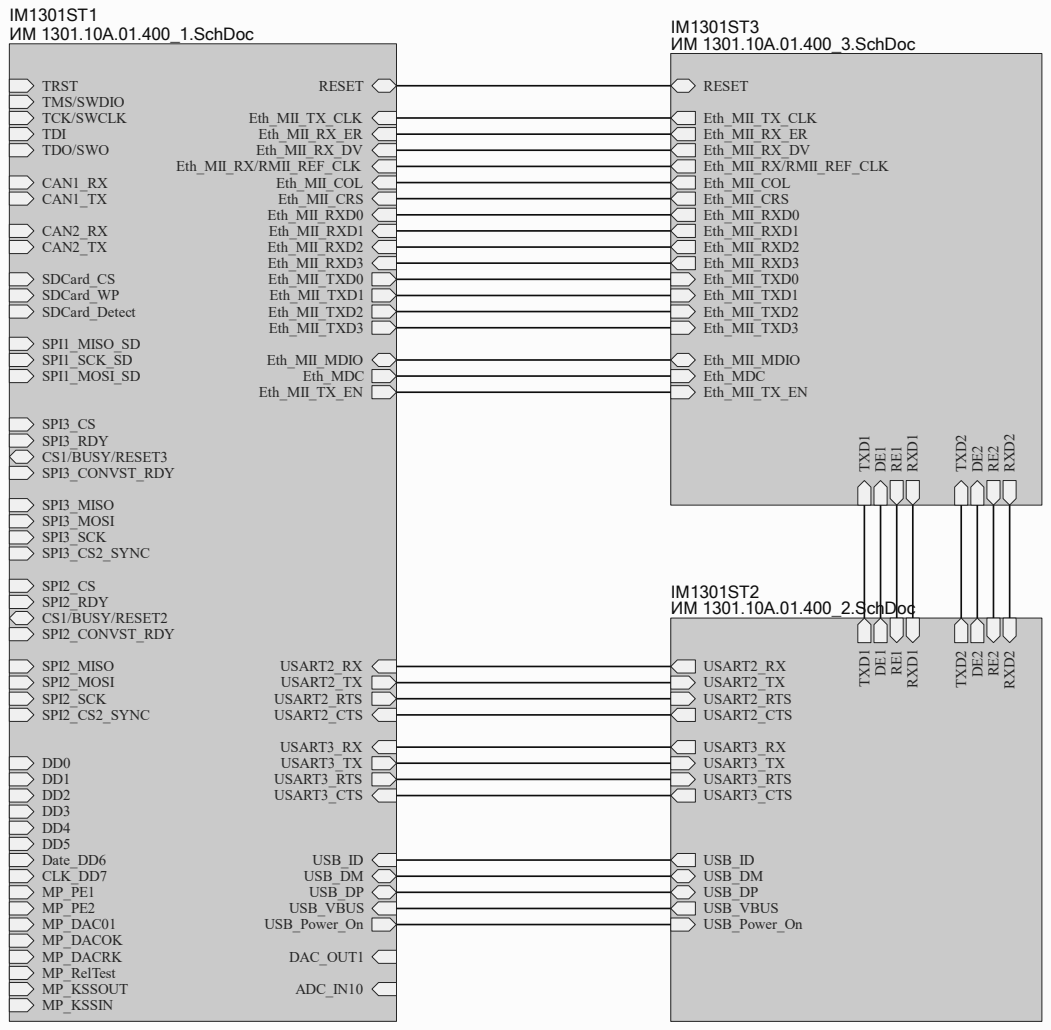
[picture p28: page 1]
Копировал; Формат А3; TRST TMS/SWDIO TCK/SWCLK TDI TDO/SWO; RESET; USART2_RX USART2_TX USART2_RTS USART2_CTS; CAN1_RX CAN1_TX; USART3_TX; USART3_RX; USART3_CTS; USART3_RTS; SDCard_Detect; SPI1_MISO_SD; USB_VBUS; USB_ID USB_DM USB_DP; Eth_MII_CRS; Eth_MII_RX/RMII_REF_CLK; Eth_MII_MDIO; Eth_MII_RX_ER; Eth_MII_TX_EN; Eth_MII_TXD0; Eth_MII_TXD3; Eth_MDC; Eth_MII_TXD2; Eth_MII_TX_CLK; USB_Power_On; SPI3_MISO; Eth_MII_RXD2 Eth_MII_RXD3; Eth_MII_RXD0 Eth_MII_RXD1; DAC_OUT1; ADC_IN10; CAN2_RX CAN2_TX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

Инв. № подл. Инв. № дубл. Подп. и дата Взам. инв. № Подп. и дата

MK_0 (1) | Лист 4

Изм. | № докум. | Подп. | Дата Лист
